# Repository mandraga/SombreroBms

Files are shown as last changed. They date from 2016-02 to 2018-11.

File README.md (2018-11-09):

# SombreroBms

SombreroBMS could have been a battery management system board and software for small electric vehicles and conversions. Mainly 36V and 48V battery packs for golf carts.
Currently an unfinished project. Reading the sensors worked and monitoring from a serial line worked. The repository has a simulation project in order to try different balancing algorithms.

Planed features:

- Lithium phosphate battery packs.
- Protection relay to connect to a power relays like a Gigavac 250A.
- State of charge updated by a current sensor during the discharge.
- Custom gauge connected with one wire + Gnd serial communication.
- Monitoring from a laptop computer using a serial communication over USB.
- Passive balancing (possibility for a heavy duty version for first balancing use).
- Undervoltage events count per battery + worst value recording.
- Powered from the battery pack.
- 10 to 18 batteries.

The development was interrupted when I moved to Lyon in 2016. And the client switched to Orion BMS, so the target was lost and the funding shorted.
However I started SombreroBMS2, simpler, safer, cheaper and easier to use. For lighter vehicles (but it will keep the same functionnality).
I will add more unit testing and simulation on it (hence the switch to gitlab). Building more on software interfaces and abstraction layers and using the test driven development aproach.
On the second version the client is myself :)

https://gitlab.com/arenyp/sombrerobms2
http://blog.vreemdelabs.com/

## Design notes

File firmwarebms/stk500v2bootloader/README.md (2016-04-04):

Bootloader code.

Note that it works with avrdude 6.3 from 2016 because SPI_MULTI is disabled.

Fuse configuration for the atmega168pa:

LB: 0xD7 Crystal with BOD
HB: 0xDD 2.7V brown out detection level
EB: 0xFA Boot block uses the last 512Words 1024Bytes

Command line used to program them:

avrdude -c stk200 -p m168p -U lfuse:w:0xD7:m
avrdude -c stk200 -p m168p -U hfuse:w:0xDD:m
avrdude -c stk200 -p m168p -U efuse:w:0xFA:m

Command line to read the fuses:

avrdude -c stk200 -p m168p -U lfuse:r:dumpfile:h

Command line to read the lockbits:

avrdude -c stk200 -p m168p -U lock:r:dumpfile:h

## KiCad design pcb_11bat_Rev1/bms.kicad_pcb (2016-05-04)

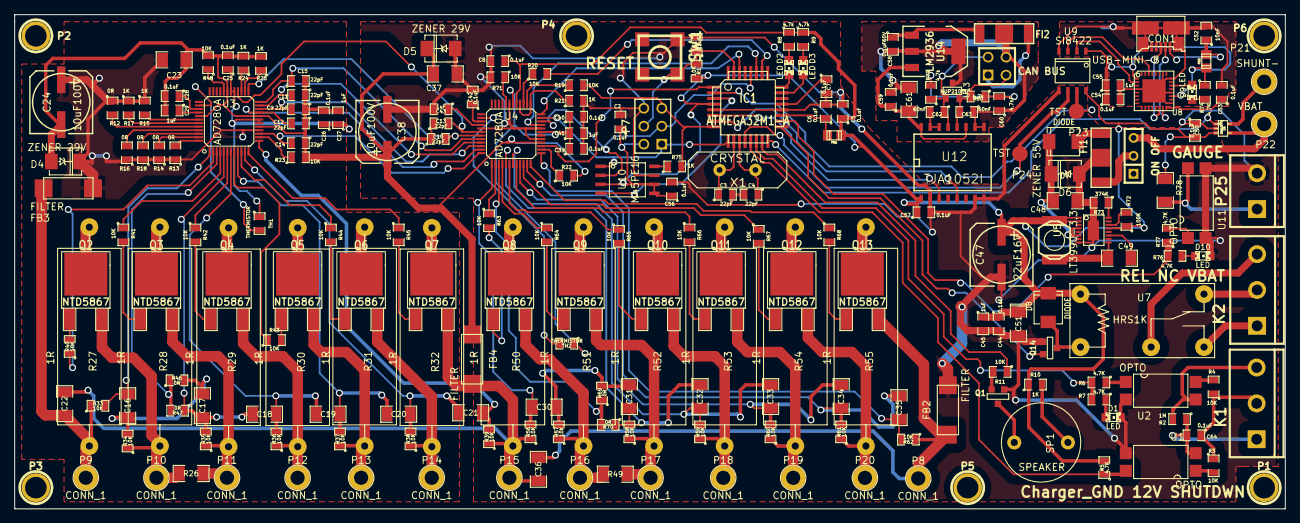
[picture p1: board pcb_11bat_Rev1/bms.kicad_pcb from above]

Board: 2 copper layers, 180.0 x 70.0 mm, 225 parts (0 on the bottom side), 171 nets.

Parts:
C1, C2, C5, C6, C7, C8, C25, C26, C28, C39, C40, C42, C44, C50, C53, C54, C56, C57, C59, C64: 0.1uF; SM0805
C3, C4, C9, C10, C11, C12, C13, C14, C15: 22pF; SM0805
C16, C17, C18, C19, C20, C21, C30, C31, C32, C33, C34, C35: 0.1uF50V; SM1206
C22, C23, C36, C37: 0.1uF100V; SM1206
C24, C38: 10uF100V; SMDHD/VF
C27, C29, C41, C43, C45, C55: 1uF; SM0805
C47: 22uF16V; SMDHD/VF
C48: 2.2uF100V; SM1206
C49: 0.22uF100V; SM1206
C51: 10uF20V; SM1206POL
C52: 10nF; SM0805
C58: 0.1uF60V; SM0805
C60: 4,7nF; SM0805
C61: 3uF; SM1206
C62, C63: 60nF; SM0805
CAN BUS: CONN_4; PIN_ARRAY_2X2
CON1: USB-MINI-B; MICRO_USB_B
D1, D2, D3, D9, D10: LED; LED-0805
D4, D5: ZENER 29V; DO-214AA(SMB)
D6: ZENER 55V; DO-214AA(SMB)
D7, D8: DIODE; DO_214AA
FB1, FB5: FILTER; c_0805
FB2, FB3, FB4: FILTER; FILTER_NFE61HT102F
FI1, FI2: EMI_FILTER2; EMI_FILTER_NFE61HT
IC1: ATMEGA32M1-A; TQFP32
K1: Charger_GND 12V SHUTDWN; bornier3
K2: REL NC VBAT; bornier3
L1: 33µH; inductor-coilcraft-DS1608
ON OFF: SWITCH_INV; MICROSWITCH_SPST
P1, P2, P3, P4, P5, P6: CONN_1; 1pin
P7: CONN_3X2; pin_array_3x2
P8, P9, P10, P11, P12, P13, P14, P15, P16, P17, P18, P19, P20: CONN_1; 1pin2mm
P21: SHUNT-; 1pin2mm
P22: VBAT; 1pin2mm
P23, P24: TST; TestP
P25: GAUGE; bornier2
Q1, Q14: BC850; SOT23EBC
Q2, Q3, Q4, Q5, Q6, Q7, Q8, Q9, Q10, Q11, Q12, Q13: NTD5867; DPAK2
R1, R3, R4, R11, R19, R20, R22, R23, R33, R34, R35, R36, R37, R38, R39, R40, R41, R42, R43, R44, R45, R48, R56, R57, R58, R59, R60, R61, R62, R63, R64, R65, R66, R67, R68, R71: 10K; SM0805
R2: 1M; SM0805
R5, R6, R7: 4.7K; SM0805
R8, R9: 4.7k; SM0805
R10, R15, R17, R21, R24, R25, R75: 1K; SM0805
R12, R13, R14, R16, R18, R46, R47, R69, R70: 0R; SM0805
R26, R49: 0R; SM1206
R27, R28, R29, R30, R31, R32, R50, R51, R52, R53, R54, R55: 1R; POW_RES
R72: 100K; SM0805
R73: 374K; SM0805
R74, R76, R77: 4,7K; SM0805
R78: 10K; SM1206
R79, R80: 4,7k; SM0805
SP1: SPEAKER; buzzer
SW1: RESET; CMSSW
TH1, TH2: THERMISTOR; SM0805
U1, U2, U11: OPTO; OPTO_CMS
U3, U4: AD7280A; LQFP48
U5: LT3990-3.3; MSOP16E
U6: INA197; sot323-5
U7: HRS1K; REL_PE014
U8: FT232RQ; QFN32-5x5
U9: SI8422; NSOP8
U10: M45PE16; SO8W
U12: TJA1052I; SO16W
U13: NUP2105L; SOT23
U14: LM2936; SOT223
X1: CRYSTAL; HC-18UV

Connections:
/AD7280A/AD7280A_SUB_HI/ALERT: R24.1, U3.27
/AD7280A/AD7280A_SUB_HI/ALERT_IO: C13.2, U3.28, U4.42
/AD7280A/AD7280A_SUB_HI/ALERThi: R15.2, U3.42
/AD7280A/AD7280A_SUB_HI/CB1: R45.1, U3.12
/AD7280A/AD7280A_SUB_HI/CB2: R44.1, U3.10
/AD7280A/AD7280A_SUB_HI/CB3: R43.1, U3.8
/AD7280A/AD7280A_SUB_HI/CB4: R42.1, U3.6
/AD7280A/AD7280A_SUB_HI/CB5: R41.1, U3.4
/AD7280A/AD7280A_SUB_HI/CB6: R40.1, U3.2
/AD7280A/AD7280A_SUB_HI/CNVST/: C15.1, U3.24, U4.44
/AD7280A/AD7280A_SUB_HI/CNVSThi/: R12.2, U3.44
/AD7280A/AD7280A_SUB_HI/CRef: C28.1, U3.39
/AD7280A/AD7280A_SUB_HI/CS/: C12.2, U3.21, U4.47
/AD7280A/AD7280A_SUB_HI/CShi/: R14.2, U3.47
/AD7280A/AD7280A_SUB_HI/HIBAT: C22.1, FB3.1, P9.1, R27.1, R33.1
/AD7280A/AD7280A_SUB_HI/MASTER: R23.1, U3.14
/AD7280A/AD7280A_SUB_HI/PD/: C14.2, U3.15, U4.48
/AD7280A/AD7280A_SUB_HI/PDhi/: R13.2, U3.48
/AD7280A/AD7280A_SUB_HI/SCLK: C9.2, U3.22, U4.46
/AD7280A/AD7280A_SUB_HI/SCLKhi: R18.2, U3.46
/AD7280A/AD7280A_SUB_HI/SDI: C11.2, U3.23, U4.45
/AD7280A/AD7280A_SUB_HI/SDIhi: R17.2, U3.43
/AD7280A/AD7280A_SUB_HI/SDO: R25.1, U3.26
/AD7280A/AD7280A_SUB_HI/SDOhi: R16.2, U3.45
/AD7280A/AD7280A_SUB_HI/VDDNFILTERED: C23.1, C24.1, D4.2, FB3.2, R12.1, R13.1, R14.1, R15.1, R16.1, R17.1, R18.1, U3.16
/AD7280A/AD7280A_SUB_HI/VDRIVE: C25.1, C26.1, C27.1, TH1.1, U3.18, U3.19, U3.29, U3.30
/AD7280A/AD7280A_SUB_HI/VIN0: C21.2, R39.2, U3.13
/AD7280A/AD7280A_SUB_HI/VIN1: C20.2, C21.1, R38.2, U3.11
/AD7280A/AD7280A_SUB_HI/VIN2: C19.2, C20.1, R37.2, U3.9
/AD7280A/AD7280A_SUB_HI/VIN3: C18.2, C19.1, R36.2, U3.7
/AD7280A/AD7280A_SUB_HI/VIN4: C17.2, C18.1, R35.2, R47.1, U3.5
/AD7280A/AD7280A_SUB_HI/VIN5: R46.1, R47.2, U3.3
/AD7280A/AD7280A_SUB_HI/VIN6: C16.1, R33.2, U3.1
/AD7280A/AD7280A_SUB_HI/VRef: C29.1, U3.40
/AD7280A/AD7280A_SUB_LO/ALERT: R20.1, U4.27
/AD7280A/AD7280A_SUB_LO/ALERT_IO: R21.1, U4.25, U4.28
/AD7280A/AD7280A_SUB_LO/CB1: R68.1, U4.12
/AD7280A/AD7280A_SUB_LO/CB2: R67.1, U4.10
/AD7280A/AD7280A_SUB_LO/CB3: R66.1, U4.8
/AD7280A/AD7280A_SUB_LO/CB4: R65.1, U4.6
/AD7280A/AD7280A_SUB_LO/CB5: R64.1, U4.4
/AD7280A/AD7280A_SUB_LO/CB6: R63.1, U4.2
/AD7280A/AD7280A_SUB_LO/CRef: C42.1, U4.39
/AD7280A/AD7280A_SUB_LO/HIBAT: C22.2, C36.1, FB4.1, P15.1, Q7.3, R39.1, R50.1, R56.1
/AD7280A/AD7280A_SUB_LO/LOBAT: C36.2, FB2.2, P8.1, Q13.3, R62.1
/AD7280A/AD7280A_SUB_LO/MASTER: R22.1, U4.14
/AD7280A/AD7280A_SUB_LO/SDIhi: C10.2, U3.25, U4.43
/AD7280A/AD7280A_SUB_LO/SDO: R19.1, U4.26
/AD7280A/AD7280A_SUB_LO/VDDNFILTERED: C9.1, C10.1, C11.1, C12.1, C13.1, C14.1, C15.2, C23.2, C24.2, C25.2, C26.2, C27.2, C28.2, C29.2, C37.1, C38.1, D4.1, D5.2, FB4.2, R22.2, R23.2, R24.2, R25.2, R48.2, U3.17, U3.20, U3.31, U3.41, U4.16
/AD7280A/AD7280A_SUB_LO/VIN0: C35.2, R62.2, U4.13
/AD7280A/AD7280A_SUB_LO/VIN1: C34.2, C35.1, R61.2, U4.11
/AD7280A/AD7280A_SUB_LO/VIN2: C33.2, C34.1, R60.2, U4.9
/AD7280A/AD7280A_SUB_LO/VIN3: C32.2, C33.1, R59.2, U4.7
/AD7280A/AD7280A_SUB_LO/VIN4: C31.2, C32.1, R58.2, R70.1, U4.5
/AD7280A/AD7280A_SUB_LO/VIN5: R69.1, R70.2, U4.3
/AD7280A/AD7280A_SUB_LO/VIN6: C30.1, R56.2, U4.1
/AD7280A/AD7280A_SUB_LO/VREG: C39.1, C40.1, C41.1, TH2.1, U4.18, U4.19, U4.30
/AD7280A/AD7280A_SUB_LO/VRef: C43.1, U4.40
/AD7280A/ALERT: IC1.26, R20.2
/AD7280A/CNVST/: IC1.30, U4.24
/AD7280A/CS/: IC1.27, U4.21
/AD7280A/PD/: IC1.1, U4.15
/AD7280A/SDI: IC1.9, P7.1, U4.23, U10.1
/AD7280A/SDO: IC1.8, P7.5, R19.2, R75.2
/BUZZER: IC1.15, R11.1
/CHARGER_12V: C64.1, K1.2, R3.1, R4.1
/CHARGER_GND: C64.2, K1.1, R2.1, U1.2
/CHARGER_ON/: IC1.13, R5.1, U1.4
/CLK1: C3.1, IC1.10, X1.2
/CLK2: C4.1, IC1.11, X1.1
/CSense/CSENSE: IC1.16, U6.1
/CSense/SHUNT-: P21.1, U6.5
/CSense/VBAT: ON OFF.3, P22.1, U6.4
/Gauge/GAUGEOUT: IC1.18, R76.1, R77.1
/Gauge/GaugeValue: P25.1, R78.2, U11.4
/Isolated_CAN/BMSCANRX: IC1.7, U12.5
/Isolated_CAN/BMSCANTX: IC1.6, U12.3
/Isolated_CAN/BMSGND: C1.2, C2.2, C3.2, C4.2, C5.2, C6.2, C7.2, C8.2, C37.2, C38.2, C39.2, C40.2, C41.2, C42.2, C43.2, C44.2, C45.2, C47.2, C48.2, C50.1, C51.2, C56.2, C57.2, D1.2, D5.1, D6.1, D10.2, FB2.1, FI1.2, IC1.5, IC1.20, P7.6, P25.2, Q1.2, Q14.2, R21.2, R71.2, R73.2, SW1.2, U1.3, U2.2, U4.17, U4.20, U4.31, U4.41, U5.8, U5.17, U6.2, U9.5, U10.7, U11.2, U11.3, U12.2, U12.7, U12.8
/Isolated_CAN/CAN12V: C58.1, FI2.1, U14.1
/Isolated_CAN/CANGND: C58.2, C59.2, C60.1, C61.2, C62.2, C63.1, CAN BUS.4, FI2.2, U12.9, U12.10, U12.14, U12.15, U13.3, U14.2, U14.4
/Isolated_CAN/CANH: C62.1, CAN BUS.2, R79.1, U12.13, U13.1
/Isolated_CAN/CANL: C63.2, CAN BUS.3, R80.2, U12.12, U13.2
/Isolated_CAN/CANUNFILTERED12V: CAN BUS.1, FI2.3
/Isolated_CAN/CANVDD: C59.1, C61.1, U12.11, U12.16, U14.3
/LEDBALANCING: D3.2, IC1.23
/LEDERROR: D2.2, IC1.24
/RESET/: C1.1, IC1.31, P7.4, R1.1, SW1.1
/SPI Flash/CLK: IC1.28, P7.3, U4.22, U10.2
/SPI Flash/CSFLASH/: IC1.3, U10.4
/SPI Flash/FSDO: R75.1, U10.8
/STOP_CHARGE: K1.3, R2.2, U2.3
/STOP_CHARGER: IC1.14, R6.2, R7.2
/VREG/3.3V: C2.1, C5.1, C8.1, C44.1, C45.1, C47.1, C50.2, C51.1, C56.1, C57.1, D8.2, FB1.2, IC1.4, L1.1, P7.2, R1.2, R5.2, R8.1, R9.1, R10.1, R72.1, R78.1, U4.29, U5.1, U5.2, U5.13, U6.3, U7.1, U9.8, U10.3, U10.5, U10.6, U12.1
/VREG/PG: R72.2, U5.14
/VREG/SW: C49.2, L1.2, U5.9
/VREG/VIN: C48.1, D6.2, D7.2, U5.4, U5.6
/comandsolenoid/COILON: IC1.17, Q14.1
/comandsolenoid/StartCOIL: K2.1, U7.4
/comandsolenoid/VbatCOIL: K2.3, U7.3
/usbserial/3V3OUT: C53.1, U8.16
/usbserial/RXD: IC1.12, P24.1, U9.6
/usbserial/TXD: IC1.2, P23.1, U9.7
/usbserial/USBGND: C52.2, C53.2, C54.2, C55.2, CON1.5, CON1.6, CON1.7, CON1.8, CON1.9, U8.4, U8.17, U8.20, U8.24, U8.26, U8.33, U9.4
/usbserial/USBVCC: C54.1, C55.1, FB5.2, R74.1, U8.1, U8.19, U9.1
unnamed: R10.2, SP1.1
unnamed: Q1.3, SP1.2
unnamed: Q1.1, R11.2
unnamed: D3.1, R9.2
unnamed: D2.1, R8.2
unnamed: C7.1, IC1.21
unnamed: D1.1, R7.1
unnamed: R3.2, U1.1
unnamed: R6.1, U2.1
unnamed: C6.1, FB1.1, IC1.19
unnamed: R4.2, U2.4
unnamed: C49.1, U5.11
unnamed: FI1.3, ON OFF.2
unnamed: R73.1, U5.16
unnamed: D7.1, FI1.1
unnamed: K2.2, U7.5
unnamed: D8.1, Q14.3, U7.2
unnamed: D9.2, U8.22
unnamed: CON1.3, U8.14
unnamed: CON1.2, U8.15
unnamed: C52.1, CON1.1, FB5.1
unnamed: D9.1, R74.2
unnamed: U8.30, U9.3
unnamed: U8.2, U9.2
unnamed: D10.1, R76.2
unnamed: R77.2, U11.1
unnamed: C60.2, R79.2, R80.1
unnamed: R48.1, U3.32
unnamed: TH1.2, U3.38
unnamed: Q5.1, R43.2
unnamed: P13.1, Q5.3, R31.1, R37.1
unnamed: Q5.2, R30.2
unnamed: Q4.1, R42.2
unnamed: P12.1, Q4.3, R30.1, R36.1
unnamed: Q4.2, R29.2
unnamed: Q7.1, R45.2
unnamed: Q7.2, R32.2
unnamed: Q6.1, R44.2
unnamed: P14.1, Q6.3, R32.1, R38.1
unnamed: Q6.2, R31.2
unnamed: Q2.2, R27.2
unnamed: Q3.2, R28.2
unnamed: P11.1, Q3.3, R26.2, R29.1, R35.1
unnamed: Q3.1, R41.2
unnamed: Q2.1, R40.2
unnamed: C16.2, C17.1, R34.2, R46.2
unnamed: P10.1, Q2.3, R26.1, R28.1, R34.1
unnamed: R71.1, U4.32
unnamed: TH2.2, U4.38
unnamed: Q13.1, R68.2
unnamed: Q12.1, R67.2
unnamed: Q11.1, R66.2
unnamed: Q10.1, R65.2
unnamed: Q9.1, R64.2
unnamed: Q8.1, R63.2
unnamed: Q9.2, R51.2
unnamed: Q10.2, R52.2
unnamed: P18.1, Q10.3, R53.1, R59.1
unnamed: Q11.2, R53.2
unnamed: Q8.2, R50.2
unnamed: P19.1, Q11.3, R54.1, R60.1
unnamed: Q12.2, R54.2
unnamed: P20.1, Q12.3, R55.1, R61.1
unnamed: Q13.2, R55.2
unnamed: C30.2, C31.1, R57.2, R69.2
unnamed: P16.1, Q8.3, R49.1, R51.1, R57.1
unnamed: P17.1, Q9.3, R49.2, R52.1, R58.1

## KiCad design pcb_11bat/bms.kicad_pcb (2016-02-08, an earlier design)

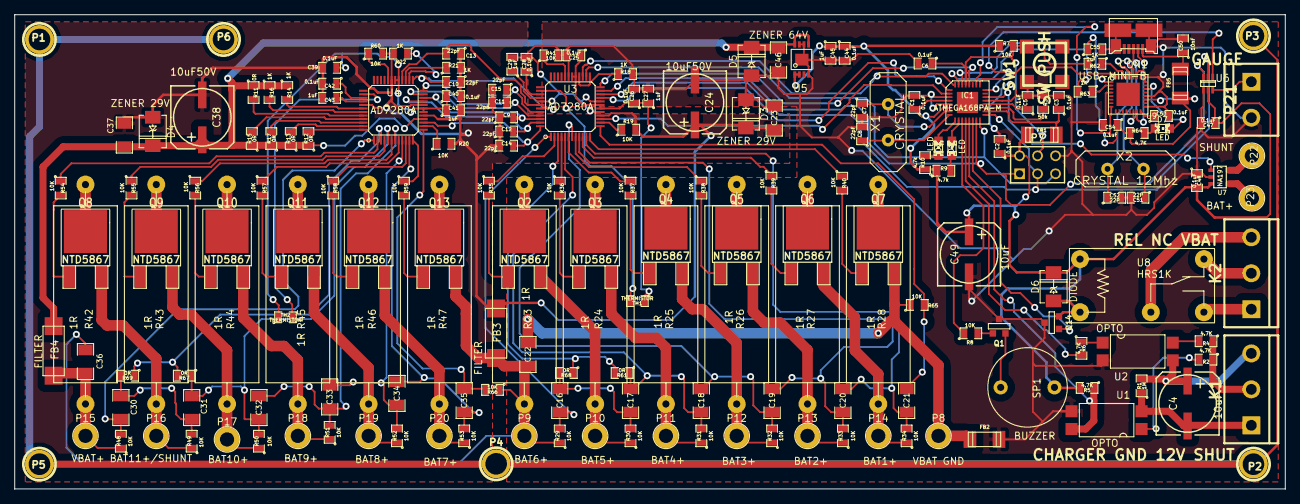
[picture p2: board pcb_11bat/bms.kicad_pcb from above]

Board: 2 copper layers, 179.5 x 67.0 mm, 192 parts (0 on the bottom side), 152 nets.

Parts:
C1, C2, C3, C5, C6, C25, C26, C28, C39, C40, C42, C44, C47, C48, C53, C54: 0.1uF; SM0805
C4, C49: 10uF; SMDHD/VF
C7, C8, C9, C10, C11, C12, C13, C14, C15: 22pF; SM0805
C16, C17, C18, C19, C20, C21, C22, C23, C30, C31, C32, C33, C34, C35, C36, C37: 0.1uF50V; SM1206
C24, C38: 10uF50V; SMDHD/VF
C27, C29, C41, C43, C45, C55: 1uF; SM0805
C46: 1uF50V; SM1206
C50: 10nF; SM0805
C51, C52: 22P; SM0805
CON1: USB-MINI-B; MICRO_USB_B
D1, D2, D7: LED; LED-0805
D3, D4: ZENER 29V; DO-214AA(SMB)
D5: ZENER 64V; DO-214AA(SMB)
D6: DIODE; DO-214AA(SMB)
FB1, FB2, FB5: FILTER; c_1808
FB3, FB4: FILTER; FILTER_NFE61HT102F
IC1: ATMEGA168PA-M; QFN32
K1: CHARGER GND 12V SHUT; bornier3
K2: REL NC VBAT; bornier3
P1, P2, P3, P4, P5, P6: CONN_1; 1pin
P7: CONN_3X2; pin_array_3x2
P8: VBAT GND; 1pin2mm
P9: BAT6+; 1pin2mm
P10: BAT5+; 1pin2mm
P11: BAT4+; 1pin2mm
P12: BAT3+; 1pin2mm
P13: BAT2+; 1pin2mm
P14: BAT1+; 1pin2mm
P15: VBAT+; 1pin2mm
P16: BAT11+/SHUNT; 1pin2mm
P17: BAT10+; 1pin2mm
P18: BAT9+; 1pin2mm
P19: BAT8+; 1pin2mm
P20: BAT7+; 1pin2mm
P21: GAUGE; bornier2
P22: SHUNT; 1pin2mm
P23: BAT+; 1pin2mm
Q1, Q14: BC550; SOT23EBC
Q2, Q3, Q4, Q5, Q6, Q7, Q8, Q9, Q10, Q11, Q12, Q13: NTD5867; DPAK2
R1: 1M; SM0805
R2, R4, R5, R6: 4.7K; SM0805
R3: 50k; SM0805
R7, R8, R19, R20, R29, R30, R31, R32, R33, R34, R35, R36, R37, R38, R39, R40, R41, R48, R49, R50, R51, R52, R53, R54, R55, R56, R57, R58, R59, R60, R65, R66: 10K; SM0805
R9, R10: 4.7k; SM0805
R11, R12, R13, R15, R17, R61, R67, R68, R69: 0R; SM0805
R14, R16, R18, R21, R22, R62, R63: 1K; SM0805
R23, R24, R25, R26, R27, R28, R42, R43, R44, R45, R46, R47: 1R; POW_RES
R64: 4,7K; SM0805
SP1: BUZZER; buzzer
SW1: SW_PUSH; CMSSW
TH1, TH2: THERMISTOR; SM0805
U1, U2: OPTO; OPTO_CMS
U3, U4: AD7280A; LQFP48
U5: LT3010-5; MSOP8E
U6: LTC2630; SC6
U7: INA197; SOT23-5
U8: HRS1K; REL_PE014
U9: FT232RQ; QFN32-5x5
X1: CRYSTAL; HC-18UV
X2: CRYSTAL 12Mhz; HC-18UV

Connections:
/AD7280A/AD7280A_SUB_HI/ALERT: R21.1, U4.27
/AD7280A/AD7280A_SUB_HI/ALERT_IO: C13.2, U3.42, U4.28
/AD7280A/AD7280A_SUB_HI/ALERThi: R14.2, U4.42
/AD7280A/AD7280A_SUB_HI/AO5.2V: C39.1, C40.1, C41.1, TH2.1, U4.18, U4.19, U4.29, U4.30
/AD7280A/AD7280A_SUB_HI/CB1: R59.1, U4.12
/AD7280A/AD7280A_SUB_HI/CB2: R58.1, U4.10
/AD7280A/AD7280A_SUB_HI/CB3: R57.1, U4.8
/AD7280A/AD7280A_SUB_HI/CB4: R56.1, U4.6
/AD7280A/AD7280A_SUB_HI/CB5: R55.1, U4.4
/AD7280A/AD7280A_SUB_HI/CB6: R54.1, U4.2
/AD7280A/AD7280A_SUB_HI/CNVST/: C15.1, U3.44, U4.24
/AD7280A/AD7280A_SUB_HI/CNVSThi/: R11.2, U4.44
/AD7280A/AD7280A_SUB_HI/CRef: C42.1, U4.39
/AD7280A/AD7280A_SUB_HI/CS/: C12.2, U3.47, U4.21
/AD7280A/AD7280A_SUB_HI/CShi/: R13.2, U4.47
/AD7280A/AD7280A_SUB_HI/HIBAT: C36.1, FB4.1, P15.1, R42.1, R48.1
/AD7280A/AD7280A_SUB_HI/MASTER: R20.1, U4.14
/AD7280A/AD7280A_SUB_HI/PD/: C14.2, U3.48, U4.15
/AD7280A/AD7280A_SUB_HI/PDhi/: R12.2, U4.48
/AD7280A/AD7280A_SUB_HI/SCLK: C9.2, U3.46, U4.22
/AD7280A/AD7280A_SUB_HI/SCLKhi: R17.2, U4.46
/AD7280A/AD7280A_SUB_HI/SDI: C11.2, U3.45, U4.23
/AD7280A/AD7280A_SUB_HI/SDIhi: R16.2, U4.43
/AD7280A/AD7280A_SUB_HI/SDO: R22.1, U4.26
/AD7280A/AD7280A_SUB_HI/SDOhi: R15.2, U4.45
/AD7280A/AD7280A_SUB_HI/VIN0: C35.2, R66.2, U4.13
/AD7280A/AD7280A_SUB_HI/VIN1: C34.2, C35.1, R53.2, U4.11
/AD7280A/AD7280A_SUB_HI/VIN2: C33.2, C34.1, R52.2, U4.9
/AD7280A/AD7280A_SUB_HI/VIN3: C32.2, C33.1, R51.2, U4.7
/AD7280A/AD7280A_SUB_HI/VIN4: C31.2, C32.1, R50.2, R67.1, U4.5
/AD7280A/AD7280A_SUB_HI/VIN5: R67.2, R69.1, U4.3
/AD7280A/AD7280A_SUB_HI/VIN6: C30.1, R48.2, U4.1
/AD7280A/AD7280A_SUB_HI/VRef: C43.1, U4.40
/AD7280A/AD7280A_SUB_LOW/ALERT_IO: R18.1, U3.25, U3.28
/AD7280A/AD7280A_SUB_LOW/AO5.2V: C25.1, C26.1, C27.1, TH1.1, U3.18, U3.19, U3.29, U3.30
/AD7280A/AD7280A_SUB_LOW/CB1: R40.1, U3.12
/AD7280A/AD7280A_SUB_LOW/CB2: R39.1, U3.10
/AD7280A/AD7280A_SUB_LOW/CB3: R38.1, U3.8
/AD7280A/AD7280A_SUB_LOW/CB4: R37.1, U3.6
/AD7280A/AD7280A_SUB_LOW/CB5: R36.1, U3.4
/AD7280A/AD7280A_SUB_LOW/CB6: R35.1, U3.2
/AD7280A/AD7280A_SUB_LOW/CRef: C28.1, U3.39
/AD7280A/AD7280A_SUB_LOW/HIBAT: C22.1, C36.2, FB3.1, P9.1, Q13.3, R23.1, R29.1, R66.1
/AD7280A/AD7280A_SUB_LOW/LOBAT: C22.2, FB2.2, P8.1, Q7.3, R65.1
/AD7280A/AD7280A_SUB_LOW/MASTER: R19.1, U3.14
/AD7280A/AD7280A_SUB_LOW/SDIhi: C10.2, U3.43, U4.25
/AD7280A/AD7280A_SUB_LOW/VDDNFILTERED: C9.1, C10.1, C11.1, C12.1, C13.1, C14.1, C15.2, C23.1, C24.1, C37.2, C38.2, C39.2, C40.2, C41.2, C42.2, C43.2, D3.2, D4.1, FB3.2, R19.2, R20.2, R21.2, R22.2, R60.2, U3.16, U4.17, U4.20, U4.31, U4.41
/AD7280A/AD7280A_SUB_LOW/VIN0: C21.2, R65.2, U3.13
/AD7280A/AD7280A_SUB_LOW/VIN1: C20.2, C21.1, R34.2, U3.11
/AD7280A/AD7280A_SUB_LOW/VIN2: C19.2, C20.1, R33.2, U3.9
/AD7280A/AD7280A_SUB_LOW/VIN3: C18.2, C19.1, R32.2, U3.7
/AD7280A/AD7280A_SUB_LOW/VIN4: C17.2, C18.1, R31.2, R61.1, U3.5
/AD7280A/AD7280A_SUB_LOW/VIN5: R61.2, R68.1, U3.3
/AD7280A/AD7280A_SUB_LOW/VIN6: C16.1, R29.2, U3.1
/AD7280A/AD7280A_SUB_LOW/VRef: C29.1, U3.40
/AD7280A/ALERT: IC1.32, U3.27
/AD7280A/CNVST/: IC1.28, U3.24
/AD7280A/CS/: IC1.1, U3.21
/AD7280A/GND: C1.2, C2.2, C3.2, C5.2, C6.2, C7.2, C8.2, C23.2, C24.2, C25.2, C26.2, C27.2, C28.2, C29.2, C44.2, C45.2, C46.2, C47.2, C48.1, C49.2, C50.2, C51.2, C52.2, C53.2, C54.2, C55.2, CON1.5, CON1.6, CON1.7, CON1.8, CON1.9, D3.1, D5.1, FB2.1, IC1.3, IC1.5, IC1.21, P7.6, P21.2, Q1.3, Q14.3, R3.1, R18.2, R41.2, SW1.2, U1.3, U2.2, U3.17, U3.20, U3.31, U3.41, U5.4, U5.6, U5.7, U5.9, U6.4, U7.2, U9.4, U9.17, U9.20, U9.24, U9.26
/AD7280A/PD/: IC1.2, U3.15
/AD7280A/SCLK: IC1.17, P7.3, U3.22, U6.2
/AD7280A/SDI: IC1.15, P7.1, U3.23, U6.3
/AD7280A/SDO: IC1.16, P7.5, U3.26
/AD7280A/VBAT: C37.1, C38.1, C46.1, D4.2, D5.2, FB4.2, R11.1, R12.1, R13.1, R14.1, R15.1, R16.1, R17.1, U4.16, U5.5, U5.8
/BUZZER: IC1.11, R8.1
/CHARGER_12V: K1.2, R2.1, R4.1
/CHARGER_GND: C4.2, K1.1, R1.1, U1.2
/CHARGER_ON/: IC1.13, R5.1, U1.4
/CSense/5V: C1.1, C2.1, C44.1, C45.1, C47.1, C48.2, C49.1, D6.2, FB1.2, IC1.4, IC1.6, P7.2, R5.2, R7.1, R9.1, R10.1, SP1.1, U5.1, U5.2, U6.5, U7.3, U8.1
/CSense/CSENSE: IC1.22, U7.1
/CSense/SHUNT-: P22.1, U7.5
/CSense/SHUNT_VBAT+: P23.1, U7.4
/LEDBALANCING: D2.2, IC1.9
/LEDERROR: D1.2, IC1.10
/RESET/: C6.1, IC1.29, P7.4, R7.2, SW1.1
/SHIELD: P1.1, P2.1, P3.1, P4.1, P5.1, P6.1
/STOP_CHARGE: C4.1, K1.3, R1.2, U2.3
/STOP_CHARGER: IC1.12, R6.2
/comandsolenoid/COILON: IC1.14, Q14.2
/comandsolenoid/StartCOIL: K2.1, U8.4
/comandsolenoid/VbatCOIL: K2.3, U8.3
/gauge/CSDAC/: IC1.24, U6.1
/gauge/GaugeValue: P21.1, U6.6
/usbserial/3V3OUT: C53.1, U9.16
/usbserial/CLEARTOSEND: IC1.26, U9.8
/usbserial/REQUESTTOSEND: IC1.25, U9.32
/usbserial/RXD: IC1.30, R62.2
/usbserial/TXD: IC1.31, R63.2
/usbserial/USBVCC: C54.1, C55.1, FB5.2, R64.1, U9.1, U9.19
unnamed: R6.1, U2.1
unnamed: R4.2, U2.4
unnamed: R2.2, U1.1
unnamed: Q1.1, SP1.2
unnamed: Q1.2, R8.2
unnamed: IC1.19, R3.2
unnamed: C3.1, FB1.1, IC1.18
unnamed: C5.1, IC1.20
unnamed: D2.1, R10.2
unnamed: D1.1, R9.2
unnamed: C7.1, IC1.7, X1.2
unnamed: C8.1, IC1.8, X1.1
unnamed: D6.1, Q14.1, U8.2
unnamed: K2.2, U8.5
unnamed: CON1.2, U9.15
unnamed: CON1.3, U9.14
unnamed: D7.2, U9.22
unnamed: C52.1, U9.28, X2.1
unnamed: R63.1, U9.2
unnamed: R62.1, U9.30
unnamed: C51.1, U9.27, X2.2
unnamed: D7.1, R64.2
unnamed: C50.1, CON1.1, FB5.1
unnamed: Q4.1, R37.2
unnamed: Q4.2, R25.2
unnamed: Q3.1, R36.2
unnamed: P11.1, Q3.3, R25.1, R31.1
unnamed: Q3.2, R24.2
unnamed: Q6.2, R27.2
unnamed: Q5.1, R38.2
unnamed: P13.1, Q5.3, R27.1, R33.1
unnamed: Q5.2, R26.2
unnamed: P12.1, Q4.3, R26.1, R32.1
unnamed: P10.1, Q2.3, R24.1, R30.1
unnamed: Q2.1, R35.2
unnamed: Q2.2, R23.2
unnamed: R41.1, U3.32
unnamed: TH1.2, U3.38
unnamed: Q7.1, R40.2
unnamed: Q7.2, R28.2
unnamed: Q6.1, R39.2
unnamed: P14.1, Q6.3, R28.1, R34.1
unnamed: C16.2, C17.1, R30.2, R68.2
unnamed: TH2.2, U4.38
unnamed: Q13.1, R59.2
unnamed: Q8.1, R54.2
unnamed: Q8.2, R42.2
unnamed: Q11.2, R45.2
unnamed: Q12.1, R58.2
unnamed: Q9.2, R43.2
unnamed: Q9.1, R55.2
unnamed: Q10.2, R44.2
unnamed: Q10.1, R56.2
unnamed: R60.1, U4.32
unnamed: Q13.2, R47.2
unnamed: P20.1, Q12.3, R47.1, R53.1
unnamed: Q12.2, R46.2
unnamed: C30.2, C31.1, R49.2, R69.2
unnamed: P16.1, Q8.3, R43.1, R49.1
unnamed: P17.1, Q9.3, R44.1, R50.1
unnamed: Q11.1, R57.2
unnamed: P18.1, Q10.3, R45.1, R51.1
unnamed: P19.1, Q11.3, R46.1, R52.1

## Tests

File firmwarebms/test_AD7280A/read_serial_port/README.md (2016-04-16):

This program only prints the text from the serial port at 9600bauds.

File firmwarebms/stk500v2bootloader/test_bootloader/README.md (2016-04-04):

This program sends a SIGNATURE command to the bootloader and then a page program command. It tests the reaction to the stk500v2 protocol and prints the returned values.

The serial port and leds should already be tested and working at this point by sending something in a loop and reading it with a terminal application to chek if it works.

The reference app note for the stk500 protocol is AVR068.pdf.

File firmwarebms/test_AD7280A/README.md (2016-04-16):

sends a report message about the AD7280A over the serial line

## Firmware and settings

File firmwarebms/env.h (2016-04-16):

// All the custom values are here

#define FIRMWARE_VERSION    0
#define FIRMWARE_SUBVERSION 1

//----------------------------------------------------------
// Value in mHom of the current measurement shunt
//----------------------------------------------------------
#define SHUNT_VAL    250L // µhoms
#define INA197GAIN    50L
#define DACREFV     5000L // 5V

//----------------------------------------------------------
// Number of monitored cells
//----------------------------------------------------------
#define CFGBATNUMBER     11

//----------------------------------------------------------
// Maximum peak current
//----------------------------------------------------------
#define MAXP_CURRENT     300L  // Amp
#define MAXC_CURRENT     180L  // Amp

#define MAXBATTERY 18
#define MAXMODULES  3

// Max AD7280A output channels for a 3 modules board
#define MAX_CHANNELS  ((6 + 3) * MAXMODULES)

// Discharge current to pass to run mode, in mA
// An hysteresis of DISCHARGE_THRESHOLD / 2 is applyed somewhere.
#define DISCHARGE_THRESHOLD 200L

// Measurements per second
#define SAMPLING_PER_SECOND  10L
#define SAMPLING_INTERVAL_MS (1000L / SAMPLING_PER_SECOND)
// Number of current measures for one hour, 10 per second
#define INTERVALS_PER_HOUR (60L * 60L * SAMPLING_PER_SECOND)

#define TEMPERATURE_HISTERESIS 15L   // °C

#define DEFAULT_CHARGE        1000
#define DEFAULT_MAX_CURRENT_A  300

#if CFGBATNUMBER==10
#define CFGAD728AMODULE_0_CHAN 5
#define CFGAD728AMODULE_1_CHAN 5
#define CFGAD728AMODULE_2_CHAN 0
#define CFGAD728AMODULES  2
#endif
#if CFGBATNUMBER==11
#define CFGAD728AMODULE_0_CHAN 6
#define CFGAD728AMODULE_1_CHAN 5
#define CFGAD728AMODULE_2_CHAN 0
#define CFGAD728AMODULES  2
#endif
#if CFGBATNUMBER==12
#define CFGAD728AMODULE_0_CHAN 6
#define CFGAD728AMODULE_1_CHAN 6
#define CFGAD728AMODULE_2_CHAN 0
#define CFGAD728AMODULES  2
#endif
#if CFGBATNUMBER==15
#define CFGAD728AMODULE_0_CHAN 5
#define CFGAD728AMODULE_1_CHAN 5
#define CFGAD728AMODULE_2_CHAN 5
#define CFGAD728AMODULES  3
#endif

//----------------------------------------------------------
// Clocks
//----------------------------------------------------------

#define BAUDRATE       9600
#ifndef F_CPU
#define F_CPU       3686000
#endif

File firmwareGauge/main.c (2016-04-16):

/******************************************************************************
 Title:    VBAT SOC led indicator
 Author:   Patrick Areny arenyp@yahoo.fr
 Date:     Mars 2016
 Software: AVR-GCC 3.3 
 Hardware: ATTINY84A using the internal 8Mhz RC clock
 Fuses:    Lo fuse SUT 10; CKSEL 0010 -> 8Mhz internal, slow rising power, CKDIV8 programmed b011000010 = 0x62
           Thus 1Mhz clock

           Hi fuse BOD at 2.5V b101   Lo = 0xDF - 2 = 0xDD

           Command line: avrdude -pt84 -P /dev/parport0 -c stk200  -Uhfuse:w:0xDD:m


 Description:
	Initialises the IO ports
        Setup a timer for 1/10 second
	Gets his display state from the delay on an input pin
        Displays on 10 led bars

*******************************************************************************/

#include <inttypes.h>
#include <stdio.h>
#include <string.h>
#include <avr/io.h>
#include <avr/interrupt.h>
#include <avr/signal.h>
#include <avr/sleep.h>
#define __DELAY_BACKWARD_COMPATIBLE__ 
#include <util/delay.h>

#include "vbat.h"
#include "main.h"

static char g_bargraph[10];

int read_adc(void)
{
  int v;

  v = 1;
  return v;
}

void State_Of_Charge_interrupt_routine(long vbat)
{
  long translated_vbat;

  translated_vbat = vbat * (1000. * CALIBRATION_V / CALIBRATION_CONV);
  fill_vbat_arr(g_bargraph, translated_vbat);
  setleds(g_bargraph);
}

void start_conversion(void)
{
  SBI(ADCSRA, ADSC);
}

void set_portA(char pin, char state)
{
  if (state == 0)
    SBI(PORTA, pin);
  else
    CBI(PORTA, pin);
}

void set_portB(char pin, char state)
{
  if (state == 0)
    SBI(PORTB, pin);
  else
    CBI(PORTB, pin);
}

void setled(char led, char state)
{
  switch (led)
    {
    case 0:
      set_portA(LED1,  state);
      break;
    case 1:
      set_portA(LED2,  state);
      break;
    case 2:
      set_portA(LED3,  state);
      break;
    case 3:
      set_portA(LED4,  state);
      break;
    case 4:
      set_portA(LED5,  state);
      break;
    case 5:
      set_portB(LED6,  state);
      break;
    case 6:
      set_portA(LED7,  state);
      break;
    case 7:
      set_portA(LED8,  state);
      break;
    case 8:
      set_portB(LED9,  state);
      break;
    case 9:
      set_portB(LED10, state);
      break;
    default:
      break;
    };
}

void setleds(char *pstates)
{
  int i;

  for (i = 0; i < 10; i++)
    setled(i, pstates[i]);
}

void toggle_leds(void)
{
  int i;

  if (g_bargraph[0] == 0)
    {
      for (i = 0; i < 10; i++)
	g_bargraph[i] = 1;
    }
  else
    {
      for (i = 0; i < 10; i++)
	g_bargraph[i] = 0;
    }
  setleds(g_bargraph);
}

// TIMER1 interrupt
ISR(TIM1_COMPA_vect)
{
  // Start aconversion, it will be completed on interrupts
  start_conversion();
  //toggle_leds();
}

// ADC interrupt
ISR(ADC_vect)
{
  unsigned long   vbat;

  //cli();
  vbat = ADCW;
  //  sei();

  //#define TESTADCINT
#ifdef  TESTADCINT
  static int e = 0;

  setled(e, 0);
  e = (e + 1) % 10;
  setled(e, 1);
#endif
  //#define SHOW_ADC_VALUE
#ifdef SHOW_ADC_VALUE
  for (int i = 0; i < 10; i++)
    setled(i, (vbat >> i) & 1);
#endif
  State_Of_Charge_interrupt_routine(vbat);
}

void configure_Timer(void)
{
  // interrupts must be disabled

  TCNT1  = 0;
  TCCR1A = 0;
  TCCR1B = 0;
  // Start timer 1 in CTC channel A mode Table 12-2
  // WGM = 0100
  TCCR1A |= (0 << WGM11) | (0 << WGM10);
  TCCR1B |= (0 << WGM13) | (1 << WGM12) | (1 << CS12);   // Prescaler Table 12-6 clkIO/256 1000000/256=3906 ticks per second

  // 16 bit counter and register
  OCR1A = 390; // CTC Compare value, interrupt triggered every 390 counts -> 10 times per second
  TIMSK1 = (1 << OCIE1A); // TIMER1 channel A interrupt enabled
  //TIFR1  = (1 << OCF1A);  // no need automaticly set and clear when the interrupt routine is called
}

/*
void enter_idle_mode(void)
{
  // cpu in idle mode, (IO clock and timers are activated)
  sleep_enable();
  sei();
  sleep_cpu();
  sleep_disable();
}
*/

void ADC_setup(void)
{
  // Power the ADC
  CBI(PRR, PRADC);
  // Digital input disabled on PA1
  SBI(DIDR0, ADC1D);
  // Free runing mode, unipolar
  ADCSRB = 0x00;
  //
  ADMUX  = (1 << MUX5) || (1 << MUX0);
  ADCSRA = (1 << ADEN);
  _delay_ms(50);
  ADCSRA = (1 << ADEN) | (0 << ADIF) | (1 << ADIE) | 0x03;
}

void mysleep(void)
{
  for (int i = 0; i < 2; i++)
    _delay_ms(50);
}

int main(void)
{
  int  m;

  cli();

  // Everything in hight impedance
  // port A:
  DDRA  = 0xFD;
  //DDRA  = (1 << LED4) | (1 << LED1);
  PORTA = 0x00;

  // port B:
  DDRB  = 0x07;
  //DDRB  = 0x00;
  PORTB = 0x00;

  // Power down
  SBI(PRR, PRTIM0); // Timer0 disabled
  SBI(PRR, PRUSI);  // Serial interface disabled

  for (m = 0; m < 10; m++)
    setled(m, 1);

  // Wait 50ms second
  _delay_ms(50);

  // ADC
  ADC_setup();

  // Timer
  configure_Timer();

  sei();                         // enable interrupts

  for (m = 0;; m++)              // loop forever
    {
//#define GNULE
#ifdef GNULE
      if (m > 9)
	m = 0;

      mysleep();

      //set_portA(LED1,  1);
      //set_portA(LED4,  1);

      //toggle_leds();

      setled(m, 1);

      mysleep();

      //toggle_leds();

      //set_portA(LED1,  0);
      //set_portA(LED4,  0);

      setled(m, 0);

      // Sleep
#endif      
    }
}

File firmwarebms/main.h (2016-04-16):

#define SBI(port, bit) ((port) |= (1 << (bit)))
#define CBI(port, bit) ((port) &= ~(1 << (bit)))

// PORTB
#define STOP_CHARGER  PB0
#define CHARGER_ON    PB1
#define RELON         PB2
#define MOSI          PB3
#define MISO          PB4
#define SCLK          PB5
#define OSC1          PB6
#define OSC2          PB7

// PORTC
#define NC0           PC0
#define GAUGE         PC1
#define RTS           PC2
#define CTS           PC3
#define NC4           PC4
#define CNVSTART      PC5
#define RESET         PC6

// PORTD
#define RXD           PD0
#define TXD           PD1
#define ALERT         PD2
#define CSBAT         PD3
#define PDOWN         PD4
#define LED_BALANCING PD5
#define LED_ERROR     PD6
#define BUZZER        PD7

// Main state machine
#define STATE_START    0
#define STATE_CHARGEON 1  // The charger is on
#define STATE_CHARGING 2  // same plus charging
#define STATE_IDLE     3  // Idle, does nothing
#define STATE_RUN      4  // Run, the current is beingused and state of charge updated
#define STATE_RELAX    5  // After run, wait for the battery voltage to spatbilise (lithium behaviour)
#define STATE_SECURITY 6  // Undervoltage or overvoltage or error like trying to start when charging
#define STATE_CURRENT_SECURITY 7  // Over current or too much current during charge
#define STATE_CRITICAL_FAILURE 8  // Stops here, no way to get out but a reset

void _delay_ms_S(int millisecond);

typedef struct  s_ibat
{
  unsigned long ibat; // milliAmps
  int           timeslice_ms;
}               t_ibat;

// EEPROM data
typedef struct  s_eeprom_data
{
  int           install_date_year;
  char          install_date_month;
  char          install_date_day;
  unsigned long bat_maxv;            // mV
  unsigned long bat_minv;
  int           bat_tmax;            // temperature °C
  int           bat_tmin;
  char          bat_elements;
  int           full_charge;         // AH
  unsigned long full_chargeV;        // mV when the pack voltage reaches this value, the charger is stoped and the charge is set at 100%
  int           max_current;         // Amp
  char          serial_number[10];   //  8 bytes             plus 0 end of string
  char          client[33];          // 32 bytes Client name plus 0 end of string
  // These are often programmed
  int           charge_cycles;
  unsigned long charge_time_minutes; // Total charging time
  int           min_temperature;     // Extreme temperatures °C
  int           max_temperature;
}               t_eeprom_data;

// Per battery eeprom information
typedef struct  s_eeprom_battery
{
  unsigned long lowestV;
  int           lowVevents; // times vbat whent under the treshold before a charge
  unsigned long cap;        // More or less the capacity, or charge speed...
}               t_eeprom_battery;

// Ram data
typedef struct  s_pack_variable_data
{
  unsigned int  uptime_days;
  unsigned int  uptime_minutes;
  unsigned int  tseconds;                 // Tenth of seconds
  int           max_discharge;            // Discharge current in Amperes
  unsigned long c_discharge;              // Discharge, last value mA
  unsigned int  state_of_charge;          // SOC mili Ampere Hour
  unsigned long vbat[MAXBATTERY];         // Batterey milivolts, last value
  unsigned long total_vbat;               // Pack voltage in mv
  int           temperature[MAXMODULES];  // °C
  char          app_state;                // State machine variable
  // Internal variables
  unsigned long c_discharge_accumulator;  // Accumulates mA per hour
  char          charging_started;         // Once started it must finish
  int           charge_time_count_tenth;  // 1/10 second
  int           charge_time_count;        // Minutes
  int           idle_counter;             // Used to get out of the relapse state
  char          prev_idle;                // Used to count the charge cycles
}               t_pack_variable_data;

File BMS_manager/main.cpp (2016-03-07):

/*
 SombreroBMS - BMS_manager
 Copyright (C) 2016 Patrick Areny
 All Rights Reserved.

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
 You should have received a copy of the GNU General Public License
 along with this program. If not, see <http://www.gnu.org/licenses/>.
*/

#include <unistd.h>
#include <string>
#include <list>
#include <vector>
#include <termios.h>

#include <time.h>

#include <tinyxml.h>

#include <FL/Fl.H>
#include <FL/Fl_Window.H>
#include <FL/Fl_Button.H>
#include <FL/Fl_File_Icon.H>
#include <FL/Fl_Native_File_Chooser.H>
#include <FL/Fl_Choice.H>
#include <FL/Fl_Tabs.H>
#include <FL/Fl_Check_Button.H>
#include <FL/Fl_Text_Buffer.H>
#include <FL/Fl_Gl_Window.H>
#include <FL/Fl_Int_Input.H>
#include <FL/Fl_Float_Input.H>

// Linux and windows
#include <SDL2/SDL.h>
#include <SDL2/SDL_ttf.h>
#include <GL/glew.h>
//
#include "gfxareas.h"
#include "mesh.h"
#include "gl2Dprimitives.h"

#include "serial/serialport.h"
#include "cfgfile.h"
//
#include "port_tab.h"
#include "about_tab.h"
#include "battery_tab.h"
#include "charge_tab.h"
#include "info_tab.h"
#include "setup_tab.h"
//
#include "SombreroBMS.h"
#include "shared.h"
#include "main.h"
#include "timer.h"
#include "thrSerial.h"

using namespace std;

void read_window_pos(t_app_data *papp_data)
{
  int x, y;
  Cxml_cfg_file_decoder *pd;
  string                 path;
  string                 ser_name;

  papp_data->xpos = papp_data->ypos = 0;
  pd = new Cxml_cfg_file_decoder();
  path = pd->get_user_config_path();
  if (pd->open_for_reading(path + string(CONFIG_FILE_NAME)))
    {
      if (pd->read_window_position(&x, &y))
	{
	  papp_data->xpos = x;
	  papp_data->ypos = y;
	}
      if (pd->read_serial_port_name(&ser_name))
	{
	  papp_data->ser_path = string(ser_name);
	}
    }
  delete pd;
}

void save_coordinates(t_app_data *pappdata)
{
  int    x, y;
  string path;

  x = pappdata->pwindow->x_root();
  y = pappdata->pwindow->y_root();
  //printf("position is %d,%d compared to %d,%d\n", x, y, pappdata->xpos, pappdata->ypos);
  if (x != pappdata->xpos || y != pappdata->ypos)
    {
      Cxml_cfg_file_decoder *pd = new Cxml_cfg_file_decoder();

      pd->open_for_writing();
      pd->write_window_position(x, y);
      if (pappdata->ser_path.size() > 0)
	pd->write_serial_port_name(pappdata->ser_path);
      path = pd->get_user_config_path();
      pd->write(path + string(CONFIG_FILE_NAME));
      delete pd;
    }
}

void close_function(void *pdata)
{
  t_app_data *papp_data = (t_app_data*)pdata;

  save_coordinates(papp_data);
  stop_serial_thread(&papp_data->shared);
  delete papp_data->shared.pBMS;
  if (papp_data->pfont)
    TTF_CloseFont(papp_data->pfont);
  papp_data->pwindow->hide(); // Close the window
}

// Alt+F4 or close cross
void wincall(Fl_Widget *pwi, void *pdata)
{
  //printf("close_callback called\n" );
  close_function(pdata);
}

void set_button(Fl_Button *pb, void* puser_data)
{
  pb->type(FL_NORMAL_BUTTON);
  //pb->labelsize(15);
  pb->user_data(puser_data);
}

int main(int argc, char **argv)
{
  int         wx, wy;
  int         border;
  Fl_Window  *window;
  t_app_data  app_data;

  app_data.path = string("./");
  //
  TTF_Init();
  app_data.pfont = TTF_OpenFont(DATAPATH MAINFONT, 14);
  if (app_data.pfont == NULL)
    {
      printf("Error: font \"%s\" is missing.\n", DATAPATH MAINFONT);
      exit(EXIT_FAILURE);
    }
  //
  app_data.pwindow        = NULL;
  app_data.shared.pserial = NULL;
  app_data.shared.pBMS    = new CSombreroBMS();
  // Layout
  Fl_File_Icon::load_system_icons();
  app_data.ser_path = string("");
  read_window_pos(&app_data);
  wx = 800;
  wy = 600;
  window = new Fl_Window(app_data.xpos, app_data.ypos, wx, wy, "BMS manager");
  app_data.pwindow = window;
  window->begin();
  //
  border = 10;
  app_data.tabs = new Fl_Tabs(border, border, wx - 2 * border, wy - 2 * border);
  // Information tab
  create_information_tab(20, 30, wx - 30, wy - 30, &app_data);

  // Charge tab
  create_charge_tab(20, 30, wx - 30, wy - 30, &app_data);

  // Battery tab
  create_battery_tab(20, 30, wx - 30, wy - 30, &app_data);

  // Setup tab
  create_setup_tab(20, 30, wx - 30, wy - 30, &app_data);
  
  // Serial port tab
  create_serialport_tab(20, 30, wx - 30, wy - 30, &app_data);

  // About tab
  create_about_tab(20, 30, wx - 30, wy - 30);

  app_data.tabs->end();
  //
  window->end();
  window->callback(wincall);
  window->user_data(&app_data);
  // Start a serial port thread so that every transfer is not blocking he interface
  start_serial_thread(&app_data.shared);
  // Start the tab refresh timer
  install_timer(&app_data);
  // Show the window
  argc = 1;
  window->show(argc, argv);
  //Fl::scheme("gtk+");
  return Fl::run();
  //return 0;
}

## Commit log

2015-11-21 Kicad schematics
    [AD7280A.sch, AD7280A_SUB.sch, CSense.sch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]
2015-11-21 Kicad modules n libs
    [ser232.sch]
2016-01-03 changed wire pins to 2mm holes, mosfet NTD5867 shcematics and filter footprint, created the pcb file for routing
    [AD7280A.sch, AD7280A_SUB.sch, CSense.sch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]
2016-01-04 placement before routing & corrected a missing resitor on vlow
    [AD7280A.sch, AD7280A_SUB.sch, CSense.sch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]
2016-01-05 fixed misplaced caps on the vins, changed some pins assignations on the avr and routed
    [AD7280A.sch, AD7280A_SUB.sch, CSense.sch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]
2016-01-06 sent to production, buzeer pad drill change, changed vias diameter
    [bms.kicad_pcb]
2016-01-23 changed the uart code to custom interrupt based code, and began to work on the rs232 protocol and eeprom writes
2016-01-25 basic features written, before the battery balancing algorithm
2016-01-25 started the balancing, added temperature and balancing state to the serial data specifications
2016-01-26 added the thermistor code, and finished the basics for battery balancing
2016-01-26 Added missing values to the serial code.
    [AD7280A.c, AD7280A.h, main.h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]
2016-02-08 Soldering components on the prototype, some changes on the schematics and component values
    [AD7280A.sch, AD7280A_SUB.sch, CSense.sch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]
2016-02-25 changed the board to add an SPI flash and 3V uC power
    [AD7280A.sch, AD7280A_SUB.sch, CSense.sch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]
2016-02-26 added serial port code to the simulator + added a switch on the Vbat power to the uController
    [AD7280A.sch, AD7280A_SUB.sch, CSense.sch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]
2016-02-28 added a serial port thread to the gui
2016-03-08 new balancing and charge functions, gauge schematic
    [vbat.sch]
2016-03-09 added a 1K resistor to the buzzer, t's frying
    [AD7280A.sch, AD7280A_SUB.sch, CSense.sch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]
2016-03-24 Bugfixes, transistor footprint, bootloader, uart unit test
    [AD7280A.sch, AD7280A_SUB.sch, CSense.sch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]
2016-03-25 change to the bootloader led
2016-03-30 + flash programing in assembler code
2016-04-04 fixed the bootloader start address (now at end of flash and not in the middle of it)
    [main.cpp, stk500boot.c]
2016-04-04 added the page flash assembler file
2016-04-04 still an address error on the bot block, works now
    [stk500boot.c]
2016-04-04 changed the uart test
2016-04-04 added led tests
2016-04-05 test led passed
2016-04-16 progress on the AD280A commands but must create a new board with an isolator on the usb bus because it fucks with every IO port on the board
    [AD7280A.sch, AD7280A_SUB.sch, CSense.sch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]
2016-04-16 New schematic in 3,3V with 2MB flash, switching regulator, usb data isolation, can bus and bug fixes
    [AD7280A.sch, AD7280A_SUB.sch, CSense.sch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]
2016-04-17 Ready to route the new schematic
    [AD7280A.sch, AD7280A_SUB.sch, CSense.sch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]
2016-05-04 New board sent to proto production
    [AD7280A.sch, AD7280A_SUB.sch, CSense.sch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]

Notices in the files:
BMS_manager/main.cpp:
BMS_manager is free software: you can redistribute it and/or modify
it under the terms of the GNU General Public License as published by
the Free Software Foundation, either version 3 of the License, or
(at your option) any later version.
